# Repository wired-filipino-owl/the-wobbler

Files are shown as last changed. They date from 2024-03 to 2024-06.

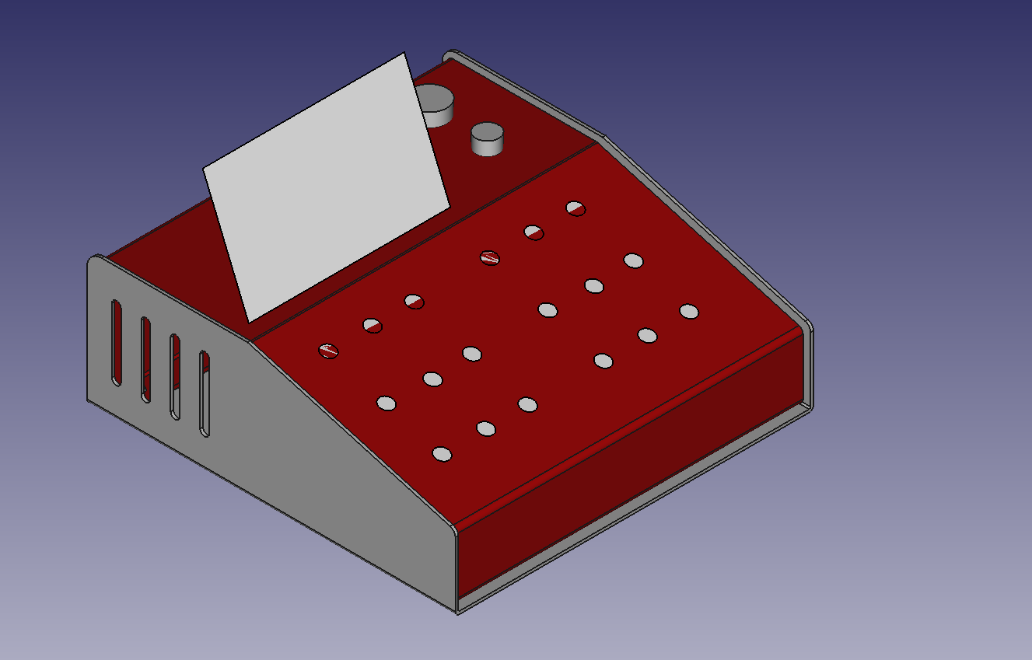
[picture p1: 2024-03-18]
model/housing_mockup.png

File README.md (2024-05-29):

# The Wobbler: Inspired by Sound Werkshop's "The Wiggler"

Project inspiration: https://www.youtube.com/watch?v=x4khM5Bjihg

My senior project at Oregon Institute of Technology, CSET Department.

----
### Software build setup
##### Install build tools
Follow [Daisy Wiki - Install the Toolchain](https://github.com/electro-smith/DaisyWiki/wiki/1.-Setting-Up-Your-Development-Environment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)
##### (Linux) Add `udev` rule for Daisy Seed to be able to program without using `sudo`
https://forum.electro-smith.com/t/linux-system-wont-program-daisy-seed-solved/5381
##### Get libraries
Clone https://github.com/electro-smith/DaisySP/ and https://github.com/electro-smith/libDaisy/ into `$HOME/lib/Daisy/`.
I suggest using `git checkout` to get the versions that match the Daisy Examples repo, otherwise the code might not compile due to version mismatch.
Build is done via `make`. The demos are dependent on the libDaisy Makefile, so make sure to put libDaisy in the right place or be prepared to edit the Makefile with the correct path.

---- 

### Non-code artifacts
Schematics are in `/schem`

More to come soon!

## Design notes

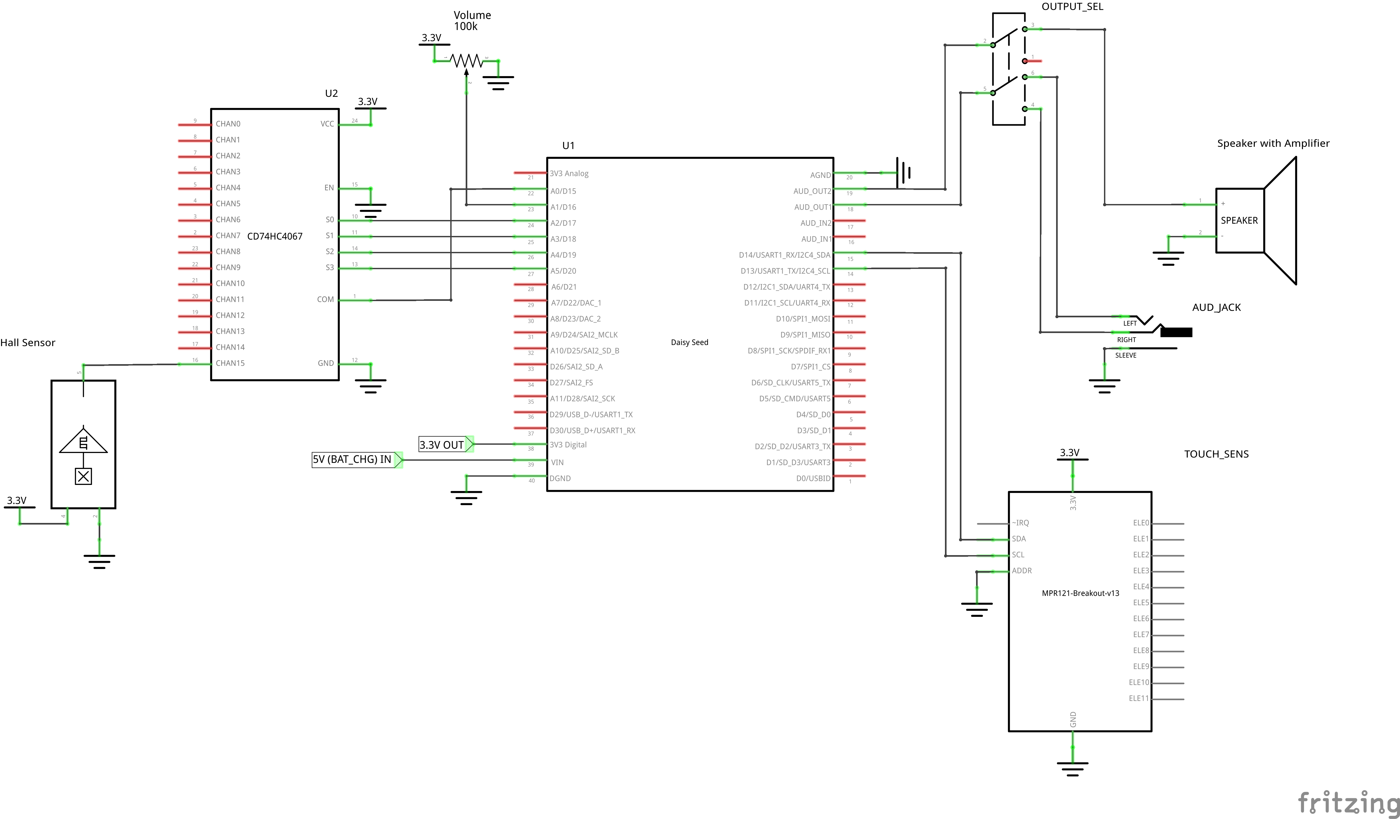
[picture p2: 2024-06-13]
schem/final_layout_schem.png

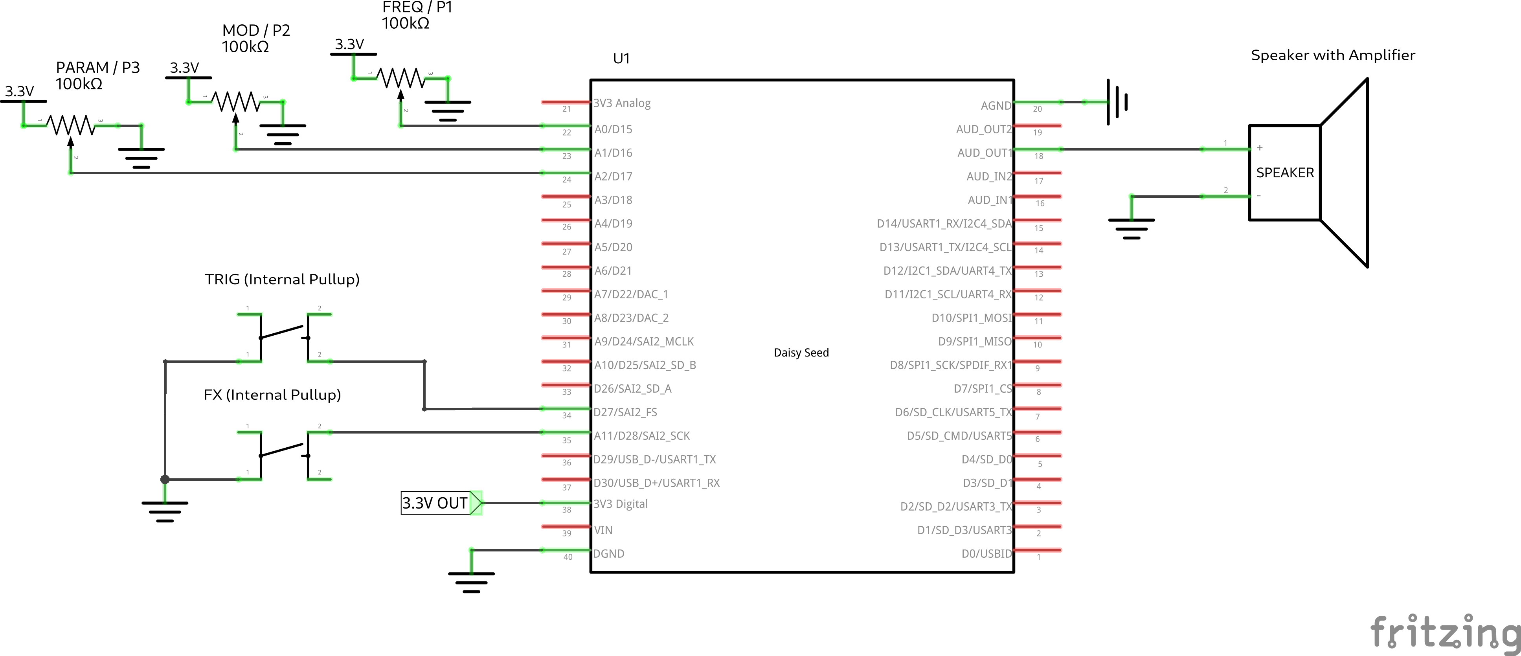
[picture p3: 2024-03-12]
schem/demo-circuit_winter24_schem_export.png

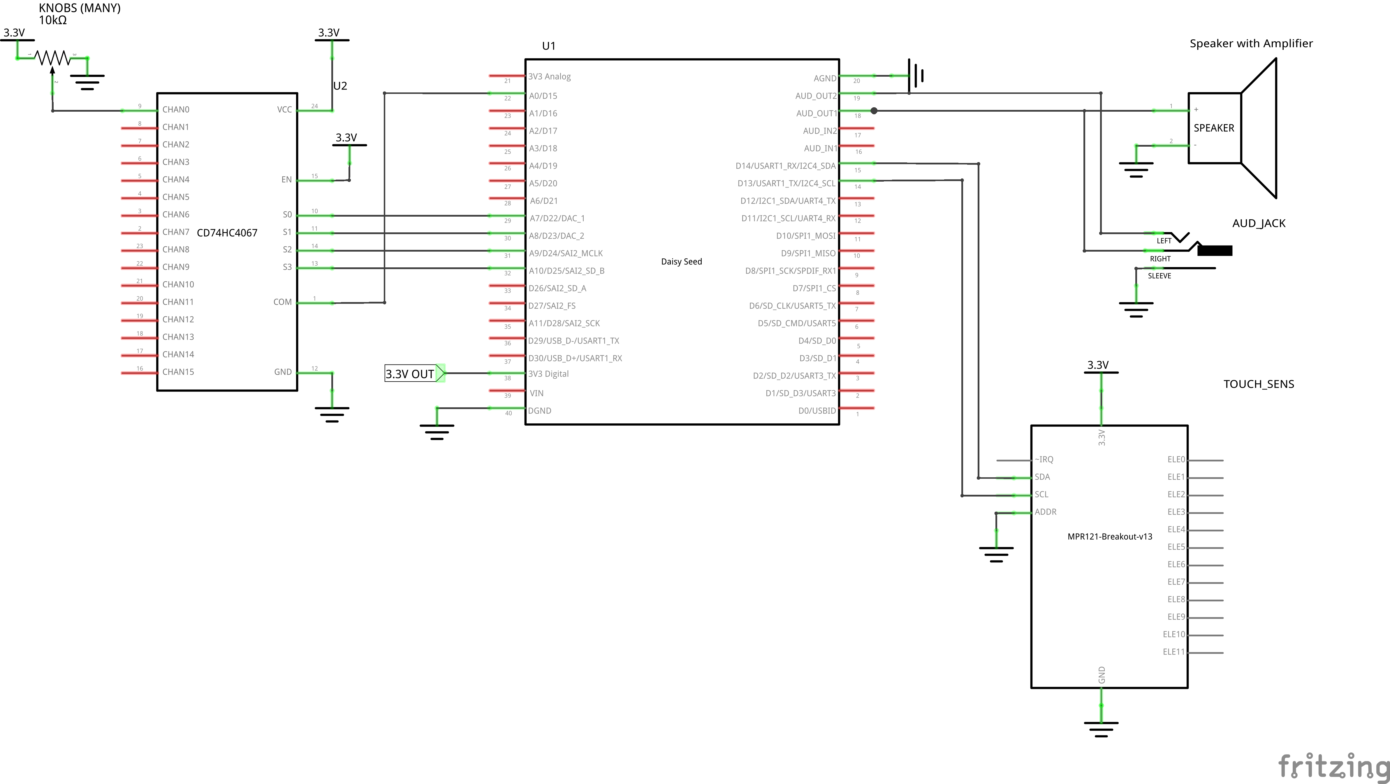
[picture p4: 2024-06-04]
schem/demodemodemo_schem_export.png

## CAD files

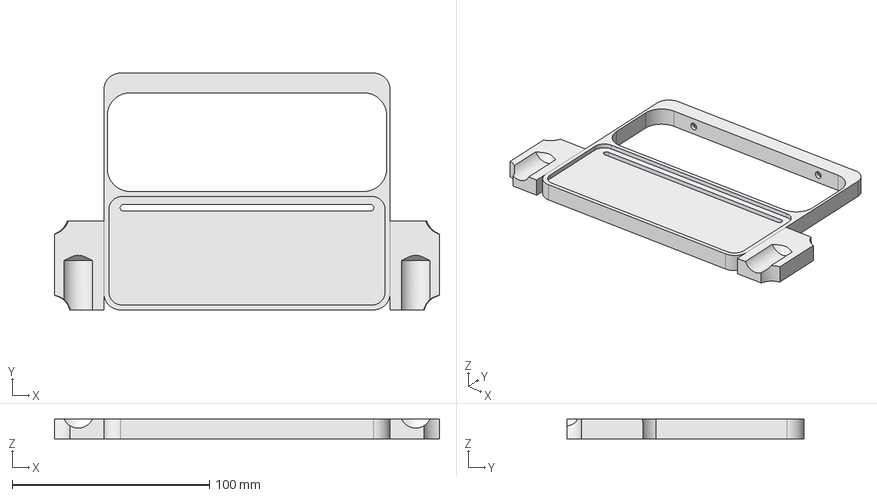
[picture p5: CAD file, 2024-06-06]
model/flexure_keyboard_plate_thumb_wings.FCStd
195.0 x 120.0 x 10.0 mm

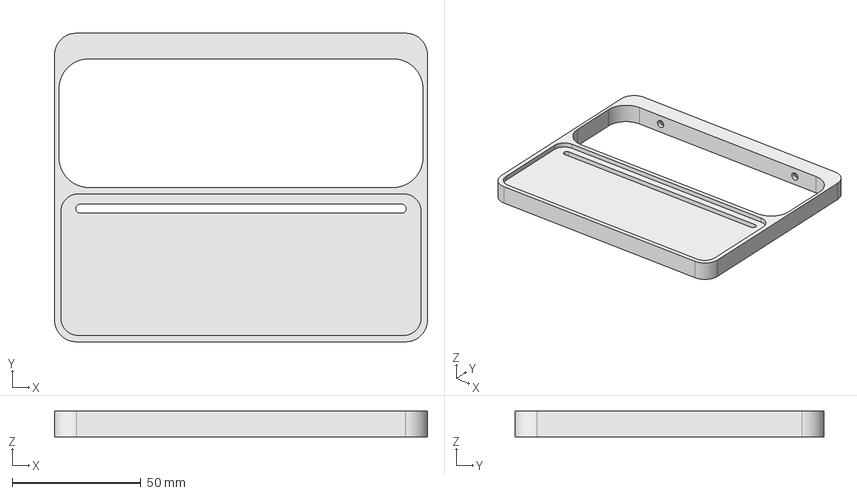
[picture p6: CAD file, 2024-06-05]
model/flexure_keyboard_plate.FCStd
145.0 x 120.0 x 10.0 mm

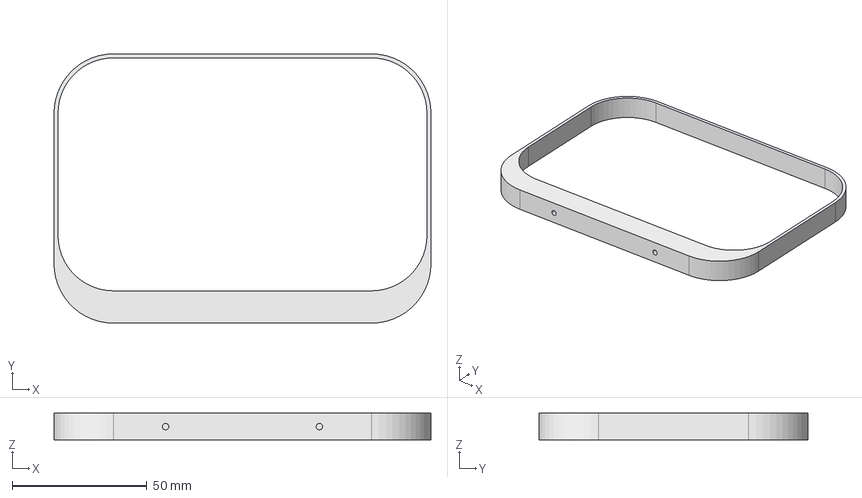
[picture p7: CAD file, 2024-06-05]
model/flexure_proto.FCStd
140.0 x 100.0 x 10.0 mm

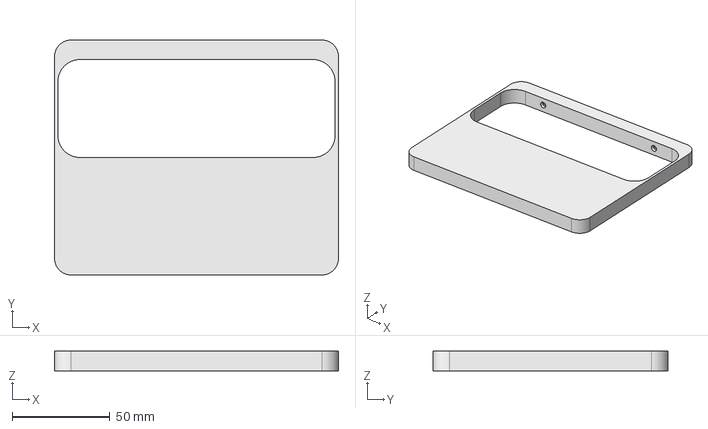
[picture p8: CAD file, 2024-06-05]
model/flexure_housing_plate.FCStd
145.0 x 120.0 x 10.0 mm

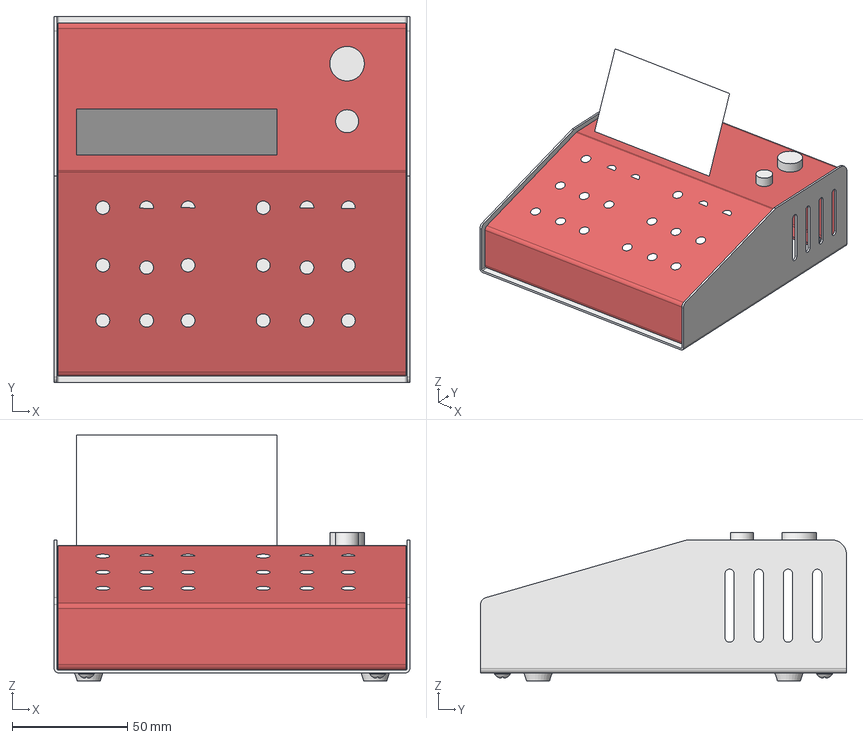
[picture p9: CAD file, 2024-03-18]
model/housing_mockup.FCStd
154.5 x 159.0 x 106.8 mm
Rectangle
Circle
Circle001
Circle002
Circle004
Circle006
Circle007
Circle008
Circle009
Circle010
Circle011
Circle012
Circle013
Circle014
Circle015
Circle016
Circle017
Circle018
Circle019
Circle020
Circle021
Circle022
Circle023
Circle024
Circle025
Circle026
Circle027
Circle028
Circle029
Circle030
Circle031
Circle032
Circle033
Circle034
Circle035
Circle036
Circle037
Circle038
Circle039
volume
power button

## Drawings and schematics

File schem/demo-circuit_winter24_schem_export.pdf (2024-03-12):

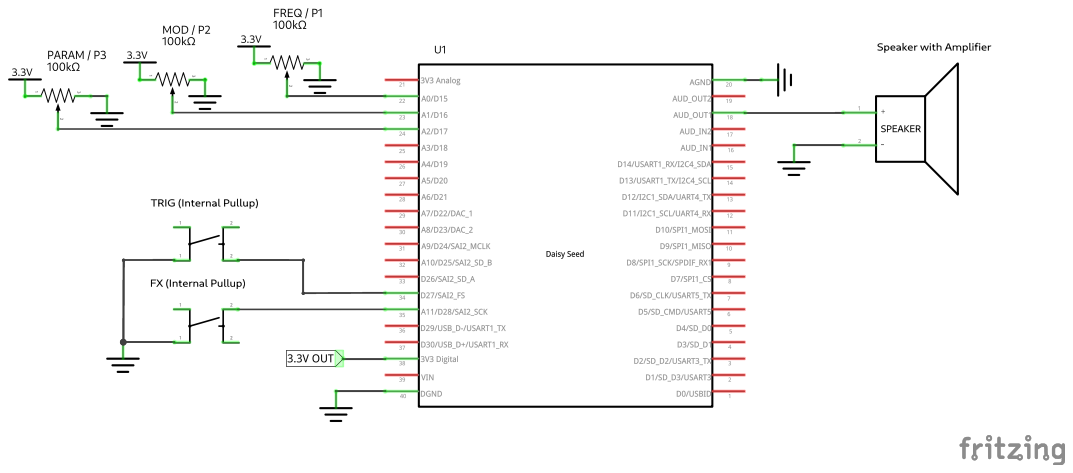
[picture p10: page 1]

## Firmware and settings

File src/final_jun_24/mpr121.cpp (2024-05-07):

#include "mpr121.h"

static uint8_t i2cdata = 0;

bool init_MPR121(I2CHandle* i2c, uint8_t addr, bool autoconfig)
{
  if (i2c == nullptr)
    return false;
  
  //reset the MPR121
  i2cdata = SOFT_RESET_MAGIC_NUMBER;
  i2c->WriteDataAtAddress(addr, SOFT_RESET, 1, &i2cdata, 1, MAX_I2C_WAIT);
  daisy::System::Delay(2); //wait for MPR121 to reset
  
  //make sure we're in stop mode, turn off all electrodes
  i2cdata = 0x00;
  i2c->WriteDataAtAddress(addr, ELECTRODE_CFG, 1, &i2cdata, 1, MAX_I2C_WAIT);
  
  //make sure that CDT Config is set to default
  i2c->ReadDataAtAddress(addr, FILTER_CDT_CFG, 1, &i2cdata, 1, MAX_I2C_WAIT);
  if(i2cdata != 0x24)
    return false;
  
  //set up touch and release thresholds
  i2cdata = TOUCH_THRESHOLD;
  for (int i = 0; i < 12; i++)
  {
    i2c->WriteDataAtAddress(addr, E0TTH + (i*2), 1, &i2cdata, 1, MAX_I2C_WAIT);
  }
  i2cdata = RELEASE_THRESHOLD;
  for (int i = 0; i < 12; i++)
  {
    i2c->WriteDataAtAddress(addr, E0RTH + (i*2), 1, &i2cdata, 1, MAX_I2C_WAIT);
  }
  
  //setup filtering baseline stuff, should probably read up on AN3889-3892 for why/how these numbers are the way they are
  //RISING
  i2cdata = 0x01;
  i2c->WriteDataAtAddress(addr, MHD_RISING, 1, &i2cdata, 1, MAX_I2C_WAIT);
  i2c->WriteDataAtAddress(addr, NHD_RISING_AMT, 1, &i2cdata, 1, MAX_I2C_WAIT);
  i2cdata = 0x0E;
  i2c->WriteDataAtAddress(addr, NCL_RISING, 1, &i2cdata, 1, MAX_I2C_WAIT);
  i2cdata = 0x00;
  i2c->WriteDataAtAddress(addr, FDL_RISING, 1, &i2cdata, 1, MAX_I2C_WAIT);
  //FALLING
  i2cdata = 0x01;
  i2c->WriteDataAtAddress(addr, MHD_FALLING, 1, &i2cdata, 1, MAX_I2C_WAIT);
  i2cdata = 0x05;
  i2c->WriteDataAtAddress(addr, NHD_FALLING_AMT, 1, &i2cdata, 1, MAX_I2C_WAIT);
  i2cdata = 0x01;
  i2c->WriteDataAtAddress(addr, NCL_FALLING, 1, &i2cdata, 1, MAX_I2C_WAIT);
  i2cdata = 0x00;
  i2c->WriteDataAtAddress(addr, FDL_FALLING, 1, &i2cdata, 1, MAX_I2C_WAIT);
  
  i2cdata = 0x00;
  i2c->WriteDataAtAddress(addr, NHD_AMT_TOUCHED, 1, &i2cdata, 1, MAX_I2C_WAIT);
  i2c->WriteDataAtAddress(addr, NCL_TOUCHED, 1, &i2cdata, 1, MAX_I2C_WAIT);
  i2c->WriteDataAtAddress(addr, FDL_TOUCHED, 1, &i2cdata, 1, MAX_I2C_WAIT);
  
  //debounce
  i2c->WriteDataAtAddress(addr, DEBOUNCE_T_R, 1, &i2cdata, 1, MAX_I2C_WAIT);
  
  //electrode charge/discharge timing and current
  i2cdata = (0b00 << FFI | 0b010000 << CDC); //16uA charge current
  i2c->WriteDataAtAddress(addr, FILTER_CDC_CFG, 1, &i2cdata, 1, MAX_I2C_WAIT);
  i2cdata = (0b001 << CDT | 0b00 << SFI | 0b000 << ESI); //0.5us encode, 1ms period
  i2c->WriteDataAtAddress(addr, FILTER_CDT_CFG, 1, &i2cdata, 1, MAX_I2C_WAIT);
  
  //setup autoconfig if it's enabled
  if (autoconfig)
  {
    i2cdata = (0b00 << AUTOCFG_FFI | 0b00 << AUTOCFG_RETRY | 0b10 << AUTOCFG_BVA 
               | 1 << AUTOCFG_ARE | 1 << AUTOCFG_ACE);
    i2c->WriteDataAtAddress(addr, AUTOCFG_0, 1, &i2cdata, 1, MAX_I2C_WAIT);
    
    i2cdata = 200; //((Vdd - 0.7)/Vdd) * 256
    i2c->WriteDataAtAddress(addr, UPSIDE_LIMIT, 1, &i2cdata, 1, MAX_I2C_WAIT);
    i2cdata = 130; //UPSIDE_LIMIT * 0.65
    i2c->WriteDataAtAddress(addr, LOWSIDE_LIMIT, 1, &i2cdata, 1, MAX_I2C_WAIT);
    i2cdata = 180; //(UPSIDE_LIMIT * 0.9
    i2c->WriteDataAtAddress(addr, TARGET_LEVEL, 1, &i2cdata, 1, MAX_I2C_WAIT);
  }
  
  i2cdata = (0b00 << ELECT_CL | 0b00 << ELECT_ELEPROX | 0b1111 << ELECT_ELE_EN); //enable all electrodes, default for CL and Proximity Detection
  i2c->WriteDataAtAddress(addr, ELECTRODE_CFG, 1, &i2cdata, 1, MAX_I2C_WAIT);
  
  return true;
}

uint16_t readTouch(I2CHandle* i2c, uint8_t addr)
{
  uint8_t reg_lo = 0;
  uint8_t reg_hi = 0;
  bool fail = 0;
  i2c->ReadDataAtAddress(addr, TOUCH_STATUS_LO, 1, &reg_lo, 1, MAX_I2C_WAIT);
  i2c->ReadDataAtAddress(addr, TOUCH_STATUS_HI, 1, &reg_hi, 1, MAX_I2C_WAIT);
  
  return (!fail ? ((reg_hi & 0x0F) << 8 | reg_lo) : -1);
}

bool setThresholds(I2CHandle* i2c, uint8_t touch, uint8_t release, uint8_t addr)
{
  bool fail = 0;
  //disable electrodes and go into stop mode so we can update registers
  i2cdata = 0x0;
  fail = (bool)i2c->WriteDataAtAddress(addr, ELECTRODE_CFG, 1, &i2cdata, 1, MAX_I2C_WAIT);
  i2cdata = touch;
  for (int i = 0; i < 12; i++)
  {
    fail = (bool)i2c->WriteDataAtAddress(addr, E0TTH + (i*2), 1, &i2cdata, 1, MAX_I2C_WAIT);
  }
  i2cdata = release;
  for (int i = 0; i < 12; i++)
  {
    fail = (bool)i2c->WriteDataAtAddress(addr, E0RTH + (i*2), 1, &i2cdata, 1, MAX_I2C_WAIT);
  }

  //turn electrodes back on and go into run mode
  i2cdata = (0b00 << ELECT_CL | 0b00 << ELECT_ELEPROX | 0b1111 << ELECT_ELE_EN);
  fail = (bool)i2c->WriteDataAtAddress(addr, ELECTRODE_CFG, 1, &i2cdata, 1, MAX_I2C_WAIT);

  return fail;
}

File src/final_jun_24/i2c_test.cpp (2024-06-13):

#include "daisy_seed.h"
#include "daisysp.h"
#include <src/per/i2c.h>
#include <cstdio>
#include "mpr121.h"

#define DEBUG_PRINT false
#define ENV_ATK_TIME 0.05F
#define ENV_DECAY_TIME 0.4F

// Use the daisy namespace to prevent having to type
// daisy:: before all libdaisy functions
using namespace daisy;
using namespace daisysp;

static DaisySeed hw;

Oscillator c5, d5, e5, f5, g5, a5, b5, c6;
Oscillator lfo;
AdEnv c5_env, d5_env, e5_env, f5_env, g5_env, a5_env, b5_env, c6_env;

uint8_t touch_lo, touch_hi = 0;

float sig, vol;
float c5_out, d5_out, e5_out, f5_out, g5_out, a5_out, b5_out, c6_out;
float lfo_out;

float hall_val = 0.0;

void AudioCallback(AudioHandle::InterleavingInputBuffer  in,
                   AudioHandle::InterleavingOutputBuffer out,
                   size_t                                size)
{
    //hw.Print(".\n");
    vol = hw.adc.GetFloat(1);
    //magic numbers are from the "at rest" value of the Hall sensor
    //and the intended midpoint frequency for the LFO
    hall_val = hw.adc.GetFloat(0);
    //hall_val = hall_val - 0.3;
    lfo.SetFreq(hall_val * 2.357 * 1.2 * 7.0);
    //lfo.SetFreq(hall_val * hall_val  * 7.0);

    if (touch_lo & 0x02)
    {
        f5_env.Trigger();
    }
    else if (touch_lo & 0x04)
    {
        e5_env.Trigger();
    }
    else if (touch_lo & 0x08)
    {
        d5_env.Trigger();
    }
    else if (touch_lo & 0x10)
    {
        c5_env.Trigger();
    }
    else if (touch_lo & 0x80)
    {
        g5_env.Trigger();
    }
    else if (touch_hi & 0x01)
    {
        a5_env.Trigger();
    }
    else if (touch_hi & 0x02)
    {
        b5_env.Trigger();
    }
    else if (touch_hi & 0x04)
    {
        c6_env.Trigger();
    }


    //Prepare the audio block
    for(size_t i = 0; i < size; i += 2)
    {
        c5.SetAmp(c5_env.Process());
        c5_out = c5.Process();
        d5.SetAmp(d5_env.Process());
        d5_out = d5.Process();
        e5.SetAmp(e5_env.Process());
        e5_out = e5.Process();
        f5.SetAmp(f5_env.Process());
        f5_out = f5.Process();
        g5.SetAmp(g5_env.Process());
        g5_out = g5.Process();
        a5.SetAmp(a5_env.Process());
        a5_out = a5.Process();
        b5.SetAmp(b5_env.Process());
        b5_out = b5.Process();
        c6.SetAmp(c6_env.Process());
        c6_out = c6.Process();

        lfo_out = lfo.Process();

        sig = c5_out + d5_out + e5_out + f5_out 
              + g5_out + a5_out + b5_out + c6_out;

        sig *= lfo_out;
        sig *= vol;
        //Set the left and right outputs to the mixed signals
        out[i]     = sig;
        out[i + 1] = sig;
    }
}

int main(void)
{
    // Configure and Initialize the Daisy Seed
    // These are separate to allow reconfiguration of any of the internal
    // components before initialization.
    hw.Configure();
    hw.Init();
    hw.StartLog(DEBUG_PRINT);
    hw.PrintLine("Hello from Daisy Seed!");
    hw.SetAudioBlockSize(4);

    //set up ADC on pin D16
    const int adcChannels = 2;
    AdcChannelConfig adcConfig[adcChannels];
    adcConfig[0].InitSingle(hw.GetPin(15));
    adcConfig[1].InitSingle(hw.GetPin(16));
    hw.adc.Init(adcConfig, adcChannels);
    hw.PrintLine("init ADC");
    hw.adc.Start();

    hw.PrintLine("started ADC");
    //set up mux (for this program, just set it to the last input)
    GPIO mux0, mux1, mux2, mux3;
    mux0.Init(seed::D17, GPIO::Mode::OUTPUT);
    mux1.Init(seed::D18, GPIO::Mode::OUTPUT);
    mux2.Init(seed::D19, GPIO::Mode::OUTPUT);
    mux3.Init(seed::D20, GPIO::Mode::OUTPUT);
    hw.PrintLine("initialized mux pins");

    mux0.Write(1);
    mux1.Write(1);
    mux2.Write(1);
    mux3.Write(1);
    hw.PrintLine("pulled mux pins high");

    //hall_val = hw.adc.GetFloat(1);
    //hw.PrintLine("ADC value from Hall sensor: %f", hall_val);

    float samplerate = hw.AudioSampleRate();
    // setup the configuration
    I2CHandle::Config i2c_conf;
    i2c_conf.periph = I2CHandle::Config::Peripheral::I2C_1;
    i2c_conf.speed  = I2CHandle::Config::Speed::I2C_400KHZ;
    i2c_conf.mode   = I2CHandle::Config::Mode::I2C_MASTER;
    i2c_conf.pin_config.scl  = {DSY_GPIOB, 8};
    i2c_conf.pin_config.sda  = {DSY_GPIOB, 9};
    // initialise the peripheral
    I2CHandle i2c;
    i2c.Init(i2c_conf);
    // now i2c points to the corresponding peripheral and can be used.

    hw.PrintLine("Attempting to setup MPR121 now.");
    bool result = init_MPR121(&i2c, MPR121_ADDR, false);
    hw.PrintLine("Result: %s", (result ? "success" : "failed!"));

#if DEBUG_PRINT == true
    uint8_t mprdata = 0;
    System::Delay(64);

    mprdata = 0;
    i2c.ReadDataAtAddress(MPR121_ADDR, AUTOCFG_0, 1, &mprdata, 1, MAX_I2C_WAIT);
    hw.Print("Autoconfig 0 Reg: ");
    hw.Print("%#X\r\n", mprdata);

    System::Delay(64);

    mprdata = 0;
    i2c.ReadDataAtAddress(MPR121_ADDR, AUTOCFG_1, 1, &mprdata, 1, MAX_I2C_WAIT);
    hw.Print("Autoconfig 1 Reg: ");
    hw.Print("%#X\r\n", mprdata);

    System::Delay(64);

    mprdata = 0;
    i2c.ReadDataAtAddress(MPR121_ADDR, ELECTRODE_CFG, 1, &mprdata, 1, MAX_I2C_WAIT);
    hw.Print("Read from Electrode Enable Reg: ");
    hw.Print("%#X\r\n", mprdata);

#endif
    //initialize oscillators
    c5.Init(samplerate);
    c5.SetWaveform(Oscillator::WAVE_TRI);
    c5.SetAmp(1); 
    c5.SetFreq(523.25);
    
    d5.Init(samplerate);
    d5.SetWaveform(Oscillator::WAVE_TRI);
    d5.SetAmp(1); 
    d5.SetFreq(587.33);

    e5.Init(samplerate);
    e5.SetWaveform(Oscillator::WAVE_TRI);
    e5.SetAmp(1); 
    e5.SetFreq(659.26);

    f5.Init(samplerate);
    f5.SetWaveform(Oscillator::WAVE_TRI);
    f5.SetAmp(1); 
    f5.SetFreq(698.46);

    g5.Init(samplerate);
    g5.SetWaveform(Oscillator::WAVE_TRI);
    g5.SetAmp(1); 
    g5.SetFreq(783.99);

    a5.Init(samplerate);
    a5.SetWaveform(Oscillator::WAVE_TRI);
    a5.SetAmp(1); 
    a5.SetFreq(880.0);

    b5.Init(samplerate);
    b5.SetWaveform(Oscillator::WAVE_TRI);
    b5.SetAmp(1); 
    b5.SetFreq(987.77);

    c6.Init(samplerate);
    c6.SetWaveform(Oscillator::WAVE_TRI);
    c6.SetAmp(1); 
    c6.SetFreq(1046.5);

    hw.PrintLine("initialized scale oscillators");

    lfo.Init(samplerate);
    lfo.SetWaveform(Oscillator::WAVE_SIN);
    lfo.SetAmp(1);
    lfo.SetFreq(10);

    hw.PrintLine("initialized lfo");

    //initialize envelopes
    c5_env.Init(samplerate);
    c5_env.SetTime(ADENV_SEG_ATTACK, ENV_ATK_TIME);
    c5_env.SetTime(ADENV_SEG_DECAY, ENV_DECAY_TIME);
    c5_env.SetMax(1);
    c5_env.SetMin(0);

    d5_env.Init(samplerate);
    d5_env.SetTime(ADENV_SEG_ATTACK, ENV_ATK_TIME);
    d5_env.SetTime(ADENV_SEG_DECAY, ENV_DECAY_TIME);
    d5_env.SetMax(1);
    d5_env.SetMin(0);

    e5_env.Init(samplerate);
    e5_env.SetTime(ADENV_SEG_ATTACK, ENV_ATK_TIME);
    e5_env.SetTime(ADENV_SEG_DECAY, ENV_DECAY_TIME);
    e5_env.SetMax(1);
    e5_env.SetMin(0);

    f5_env.Init(samplerate);
    f5_env.SetTime(ADENV_SEG_ATTACK, ENV_ATK_TIME);
    f5_env.SetTime(ADENV_SEG_DECAY, ENV_DECAY_TIME);
    f5_env.SetMax(1);
    f5_env.SetMin(0);

    g5_env.Init(samplerate);
    g5_env.SetTime(ADENV_SEG_ATTACK, ENV_ATK_TIME);
    g5_env.SetTime(ADENV_SEG_DECAY, ENV_DECAY_TIME);
    g5_env.SetMax(1);
    g5_env.SetMin(0);

    a5_env.Init(samplerate);
    a5_env.SetTime(ADENV_SEG_ATTACK, ENV_ATK_TIME);
    a5_env.SetTime(ADENV_SEG_DECAY, ENV_DECAY_TIME);
    a5_env.SetMax(1);
    a5_env.SetMin(0);

    b5_env.Init(samplerate);
    b5_env.SetTime(ADENV_SEG_ATTACK, ENV_ATK_TIME);
    b5_env.SetTime(ADENV_SEG_DECAY, ENV_DECAY_TIME);
    b5_env.SetMax(1);
    b5_env.SetMin(0);

    c6_env.Init(samplerate);
    c6_env.SetTime(ADENV_SEG_ATTACK, ENV_ATK_TIME);
    c6_env.SetTime(ADENV_SEG_DECAY, ENV_DECAY_TIME);
    c6_env.SetMax(1);
    c6_env.SetMin(0);

    //wait 2 seconds for MPR121 to get baseline values
    System::Delay(2000);
    //Start calling the callback function
    hw.StartAudio(AudioCallback);
    hw.PrintLine("started Audio Callback");

    // Loop forever
    while(1)
    {
	hw.PrintLine("At top of While loop");
   	hw.SetLed(readTouch(&i2c) > 0);  
	//wait for touch
	touch_hi = touch_lo = 0;
	while(readTouch(&i2c) == 0)
	{
		System::Delay(64);
	}
	i2c.ReadDataAtAddress(MPR121_ADDR, TOUCH_STATUS_LO, 1, &touch_lo, 1, MAX_I2C_WAIT);
    	hw.PrintLine("Read from TOUCH_REG_LO : 0x%X", touch_lo);
	i2c.ReadDataAtAddress(MPR121_ADDR, TOUCH_STATUS_HI, 1, &touch_hi, 1, MAX_I2C_WAIT);
    	hw.PrintLine("Read from TOUCH_REG_HI: 0x%X", touch_hi);
	System::Delay(64);
        //hall_val = hw.adc.GetFloat(0);
        hw.PrintLine("ADC value from Hall sensor: %d",  hw.adc.Get(0));
        hw.PrintLine("Simulated LFO frequency: %d", int(hall_val * 2.357 * 8));
    }
}

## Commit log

2024-03-12 Demo schematic
    [demo-circuit_winter24.fzz]
2024-03-12 Hit the 'Flip' button instead of 'Rotate' - oops
    Fixed the schematic so it actually matches real life
    [demo-circuit_winter24.fzz]
2024-03-13 Flexure first prototype model -- thanks to Albert Briscoe for FreeCAD help
    [flexure_proto.FCStd]
2024-03-13 Add FCBak files to gitignore
    [flexure_proto.FCStd]
2024-03-18 Add housing mockup model
    [housing_mockup.FCStd]
2024-05-05 I2C Test - currently doesn't work properly
    [i2c_test.cpp]
2024-05-05 Touch Sensor - figured out that address is 7 bit, now we can talk to it
2024-05-06 I2C MPR121 basic implementation, untested
2024-05-06 I2C MPR121 library, still doesn't build properly
    [i2c_test.cpp, mpr121.cpp]
2024-05-07 Added mpr121 library to makefile, fixed build errors
    [mpr121.cpp]
2024-05-07 I2C Test - Gangster Edition
2024-05-07 Undeleted i2c_test.cpp
2024-05-07 Cleanup MPR121 library and make i2c demo work without serial terminal connected
2024-05-25 Cleaned up I2C test and added touch trigger demo
2024-06-04 poster schematic and pd for keyboard
    [demodemodemo.fzz]
2024-06-04 keyboard pd - switch to hv oscillator to do different shapes
2024-06-05 Not fucked up flexure with NEW SCREW HOLES!!!
    [flexure_proto.FCStd]
2024-06-05 3d models for flexure prototypes
    [flexure_housing_plate.FCStd, flexure_keyboard_plate.FCStd, flexure_proto.FCStd]
2024-06-06 Flexure - added thumb thingies
    [flexure_keyboard_plate_thumb_wings.FCStd]
2024-06-11 saw_touch - change case statements to ifs and masking
2024-06-13 Saw touch - Hall sensor now controls an LFO
2024-06-13 Schematics - added final assembly version
    [final_layout.fzz]
